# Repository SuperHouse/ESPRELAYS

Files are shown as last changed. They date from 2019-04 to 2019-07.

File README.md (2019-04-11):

ESPRELAYS: ESP8266 Reed Relay Board
====================================

Copyright 2017-2019 SuperHouse Automation Pty Ltd  www.superhouse.tv  

Allows an appliance remote control to be connected to an ESP8266 so that it
can be triggered remotely as if the buttons were pushed.

Features:

 * ESP8266 MCU with wifi.
 * 6 dry-contact reed relay outputs.
 * Headers for GND, 3.3V, and 5V to power the remote control.
 * 2.1mm DC jack for 7-24Vdc power input.
 * Efficient 5V switchmode power supply with 3.3V linear regulator.

More information is available at:

  http://www.superhouse.tv/esprelays

INSTALLATION
------------
The design is saved as an EAGLE project. EAGLE PCB design software is
available from www.cadsoftusa.com free for non-commercial use. To use
this project download it and place the directory containing these files
into the "eagle" directory on your computer.

DISTRIBUTION
------------
The specific terms of distribution of this project are governed by the
license referenced below.

LICENSE
-------
Licensed under the TAPR Open Hardware License (www.tapr.org/OHL).
The "license" folder within this repository also contains a copy of
this license in plain text format.

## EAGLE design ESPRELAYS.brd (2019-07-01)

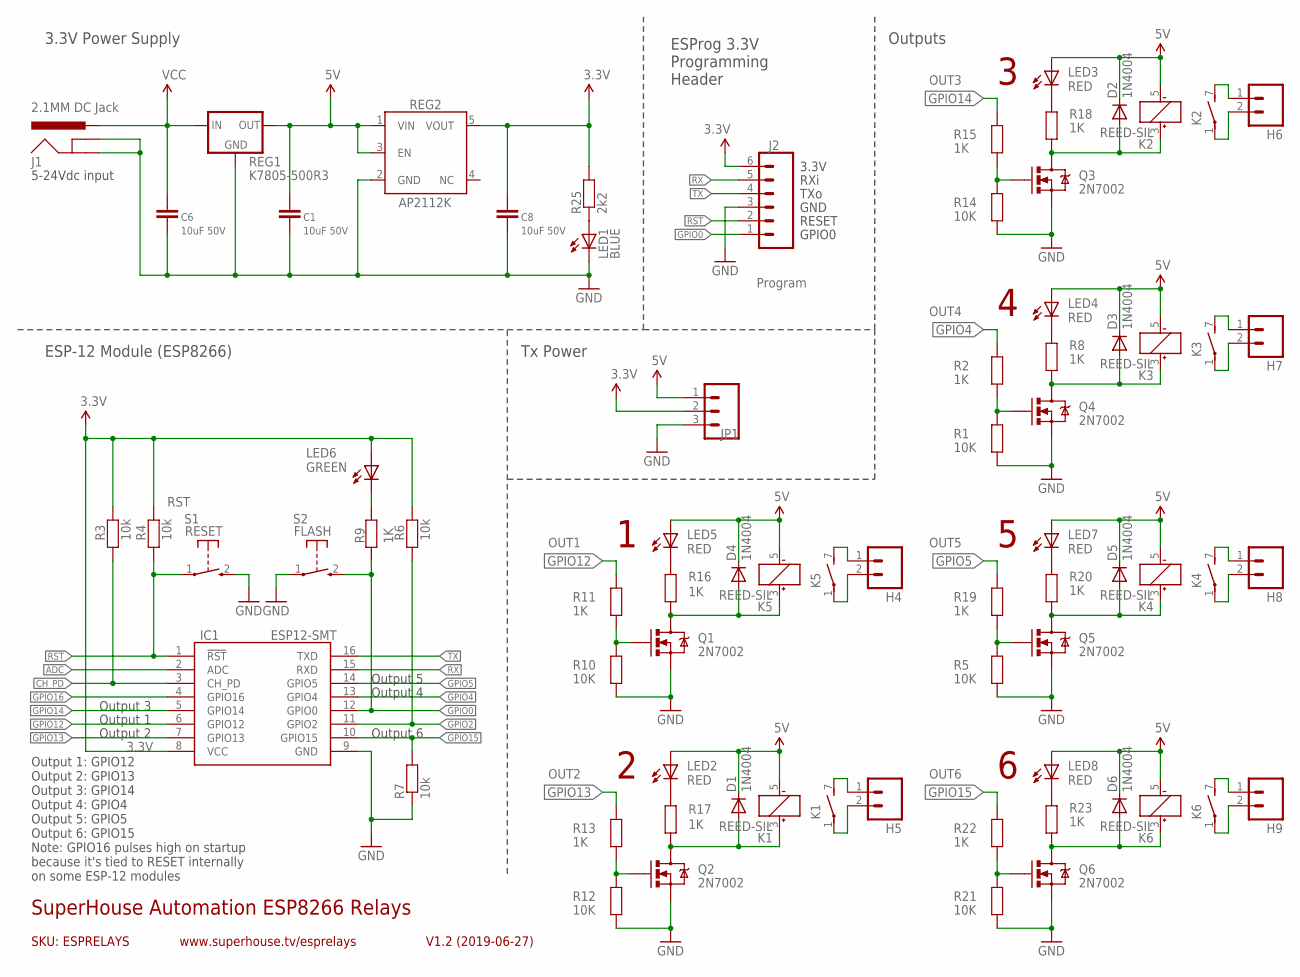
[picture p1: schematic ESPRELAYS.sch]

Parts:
C1, C6, C8: 10uF 50V; C0805
D1, D2, D3, D4, D5, D6: 1N4004; SMA-DIODE
H4, H5, H6, H7, H8, H9: M02-PIN; 1X02-P
IC1: ESP12-SMT; ESP12
J1: 2.1MM DC Jack; POWER_JACK_SLOTS
J2: Program; 1X06-S
JP1: M03-PLAIN; 1X03
K1, K2, K3, K4, K5, K6: REED-SIL; REED
LED1: BLUE; LED-0603
LED2, LED3, LED4, LED5, LED7, LED8: RED; LED-0603
LED6: GREEN; LED-0603
Q1, Q2, Q3, Q4, Q5, Q6: 2N7002; SOT23-3
R1, R5, R10, R12, R14, R21: 10K; R0603
R2, R8, R9, R11, R13, R15, R16, R17, R18, R19, R20, R22, R23: 1K; R0603
R3, R4, R6, R7: 10k; R0603
R25: 2k2; R0603
REG1: K7805-500R3; K78XX-500R3
REG2: AP2112KSOT25; SOT23-5
S1: RESET; TACTILE_SMD_3X4X2
S2: FLASH; TACTILE_SMD_3X4X2

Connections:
3.3V: C8.1, IC1.8 (VCC), J2.6, JP1.2, LED6.A, R3.2, R4.2, R6.2, R25.2, REG2.5 (VOUT)
5V: C1.1, D1.C, D2.C, D3.C, D4.C, D5.C, D6.C, JP1.1, K1.5 (-), K2.5 (-), K3.5 (-), K4.5 (-), K5.5 (-), K6.5 (-), LED2.A, LED3.A, LED4.A, LED5.A, LED7.A, LED8.A, REG1.3 (OUT), REG2.1 (VIN), REG2.3 (EN)
ADC: IC1.2 (ADC)
CH_PD: IC1.3 (CH_PD), R3.1
GND: C1.2, C6.2, C8.2, IC1.9 (GND), J1.GND, J1.GNDBREAK, J2.3, JP1.3, LED1.C, Q1.2 (S), Q2.2 (S), Q3.2 (S), Q4.2 (S), Q5.2 (S), Q6.2 (S), R1.1, R5.1, R7.1, R10.1, R12.1, R14.1, R21.1, REG1.2 (GND), REG2.2 (GND), S1.2 (S), S2.1
GPIO0: IC1.12 (GPIO0), J2.1, R9.2, S2.2 (S)
GPIO2: IC1.11 (GPIO2), R6.1
GPIO4: IC1.13 (GPIO4), R2.2
GPIO5: IC1.14 (GPIO5), R19.2
GPIO12: IC1.6 (GPIO12), R11.2
GPIO13: IC1.7 (GPIO13), R13.2
GPIO14: IC1.5 (GPIO14), R15.2
GPIO15: IC1.10 (GPIO15), R7.2, R22.2
GPIO16: IC1.4 (GPIO16)
unnamed: Q1.1 (G), R10.2, R11.1
unnamed: Q2.1 (G), R12.2, R13.1
unnamed: H5.1, K1.7 (S)
unnamed: LED3.C, R18.1
unnamed: H5.2, K1.1
unnamed: H6.1, K2.7 (S)
unnamed: Q4.1 (G), R1.2, R2.1
unnamed: H4.1, K5.7 (S)
unnamed: H6.2, K2.1
unnamed: Q3.1 (G), R14.2, R15.1
unnamed: LED4.C, R8.1
unnamed: H4.2, K5.1
unnamed: H7.1, K3.7 (S)
unnamed: H7.2, K3.1
unnamed: H8.1, K4.7 (S)
unnamed: H8.2, K4.1
unnamed: H9.1, K6.7 (S)
unnamed: H9.2, K6.1
unnamed: Q5.1 (G), R5.2, R19.1
unnamed: LED7.C, R20.1
unnamed: LED2.C, R17.1
unnamed: Q6.1 (G), R21.2, R22.1
unnamed: LED1.A, R25.1
unnamed: LED5.C, R16.1
unnamed: LED8.C, R23.1
unnamed: LED6.C, R9.1
OUT1: D4.A, K5.3 (+), Q1.3 (D), R16.2
OUT2: D1.A, K1.3 (+), Q2.3 (D), R17.2
OUT3: D2.A, K2.3 (+), Q3.3 (D), R18.2
OUT4: D3.A, K3.3 (+), Q4.3 (D), R8.2
OUT5: D5.A, K4.3 (+), Q5.3 (D), R20.2
OUT6: D6.A, K6.3 (+), Q6.3 (D), R23.2
RST: IC1.1 (!RST), J2.2, R4.1, S1.1
RX: IC1.15 (RXD), J2.5
TX: IC1.16 (TXD), J2.4
VCC: C6.1, J1.PWR, REG1.1 (IN)

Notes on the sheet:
SKU: ESPRELAYS
SuperHouse Automation ESP8266 Relays
V1.2 (2019-06-27)
www.superhouse.tv/esprelays
3.3V Power Supply
Outputs
ESP-12 Module (ESP8266)
ESProg 3.3V Programming Header
5-24Vdc input
Output 1: GPIO12 Output 2: GPIO13 Output 3: GPIO14 Output 4: GPIO4 Output 5: GPIO5 Output 6: GPIO15 Note: GPIO16 pulses high on startup because it's tied to RESET internally on some ESP-12 modules
Output 1
Output 2
Output 3
Output 4
Output 5
Output 6
Tx Power
3.3V
RXi
TXo
GND
RESET
GPIO0

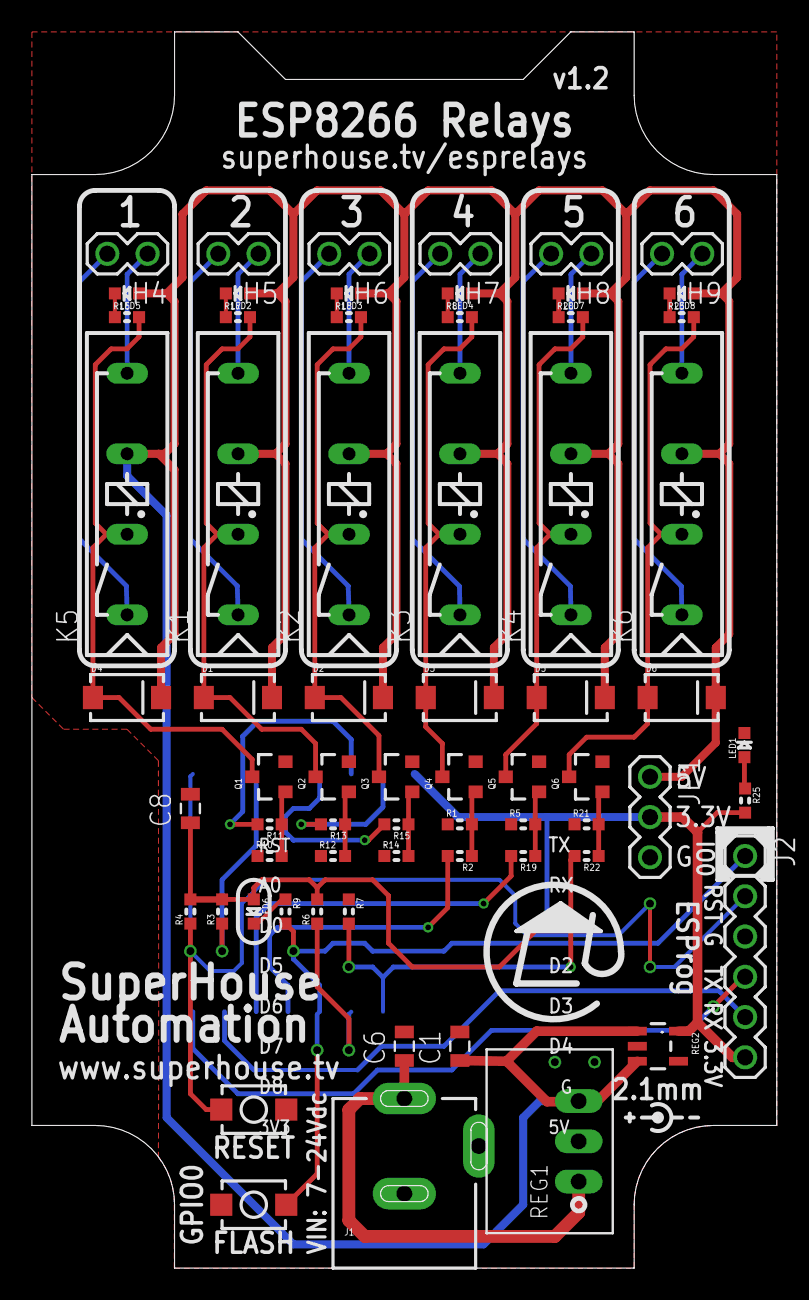
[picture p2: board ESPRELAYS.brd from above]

Board: 2 copper layers, 47.0 x 78.0 mm, 67 parts (1 on the bottom side), 48 nets.

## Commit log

2019-02-19 Added reed relays
    [ESPREMOTE.brd, ESPREMOTE.sch]
2019-02-19 Renamed project files
    [ESPRELAYS.brd, ESPRELAYS.sch]
2019-02-19 Added SIP reed relays
    [ESPRELAYS.brd, ESPRELAYS.sch]
2019-04-11 Routing for v1.0 release
    [ESPRELAYS.brd, ESPRELAYS.sch]
2019-04-17 Improved value designators
    [ESPRELAYS.brd]
2019-04-26 Changed output pins to avoid GPIO16 because it pulses on startup. v1.1 release
    [ESPRELAYS.brd, ESPRELAYS.sch]
2019-06-01 Fixed revision number in schematic
    [ESPRELAYS.sch]
2019-07-01 Replaced most parts using SuperHouse library to add 3D models
    [ESPRELAYS.brd, ESPRELAYS.sch]

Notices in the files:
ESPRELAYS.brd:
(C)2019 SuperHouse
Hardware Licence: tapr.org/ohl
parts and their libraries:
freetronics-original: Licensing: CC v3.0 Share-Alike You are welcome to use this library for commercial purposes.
